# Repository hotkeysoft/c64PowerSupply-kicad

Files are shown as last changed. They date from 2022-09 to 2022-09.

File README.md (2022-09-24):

# C64 Power Supply
Rev B September 2022

### Basic Tests: complete

This was version was built and tested 40 minutes @ 2.5A on the 5V line with no issue. 
- Heat dissipation could be a problem in an plastic enclosure, will need more tests.
  - Regulator dissipates heat through ground plane so a metal case (and metal stand-offs) could be enough

### Simple Switching Power Supply
- 120/240VAC Input (toggle with jumpers)
- Beefier transformer (56VA)
- TVS diodes on both transformer output lines (optional)
- MOV and filtering cap on input side (optional)
- 9VAC Output 1.5A Max w/Fuse
- 5VDC Output 3A Max w/Fuse, more than enough for C128
- +5V Adjustable with trimmer
- BD9E303EFJ Buck switching regulator for +5V output
  - In theory more efficient than old LM2596T, tests will tell 
- Two terminal blocks to use the power supply with either a C64 or a C128
  - *NOT* at the same time...
    - 9VAC line should be fine in theory (transformer can provide 3A). Altough noise/crosstalk could be an issue.
    - 5V line could overload. The max capacity of this switching regulator is 3A. C128 uses around 2A by itself, with nothing connected. C64 is rated to use 1.5A. Not responsible if someone powers both at the same time.

Images
============
|Front | Back |
|---|---|
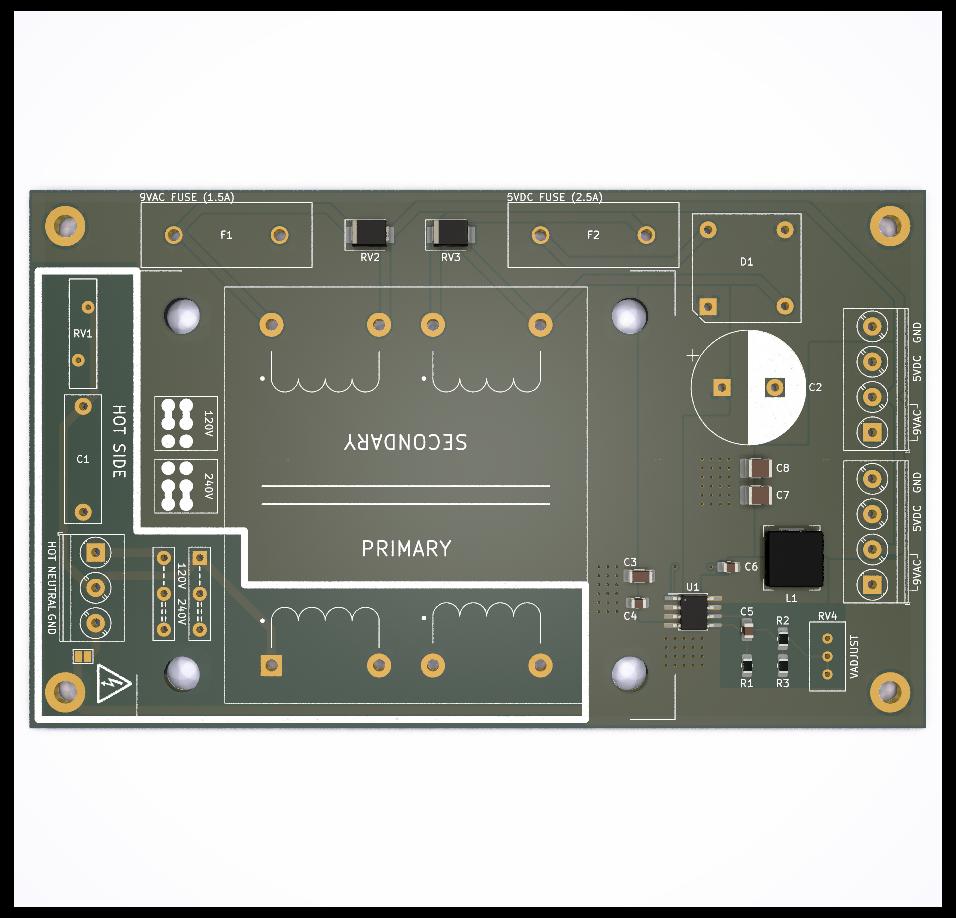
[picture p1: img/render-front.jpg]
Render Front
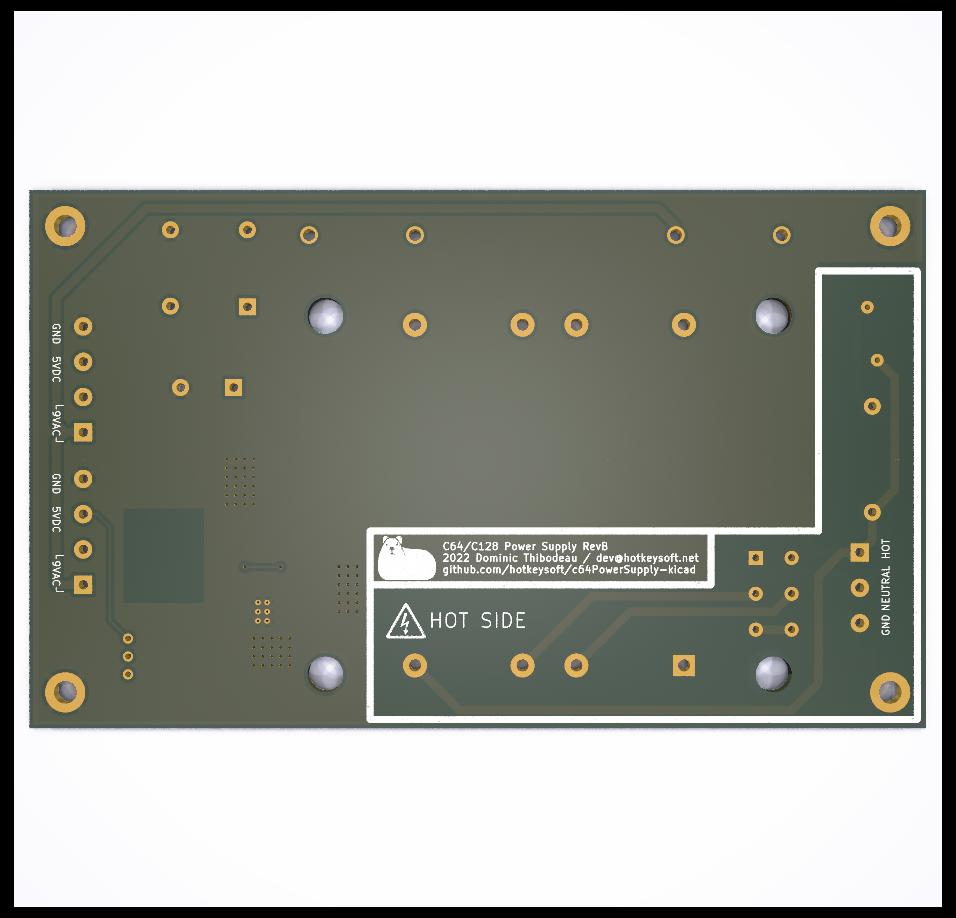
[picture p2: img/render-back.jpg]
Render Back
|||

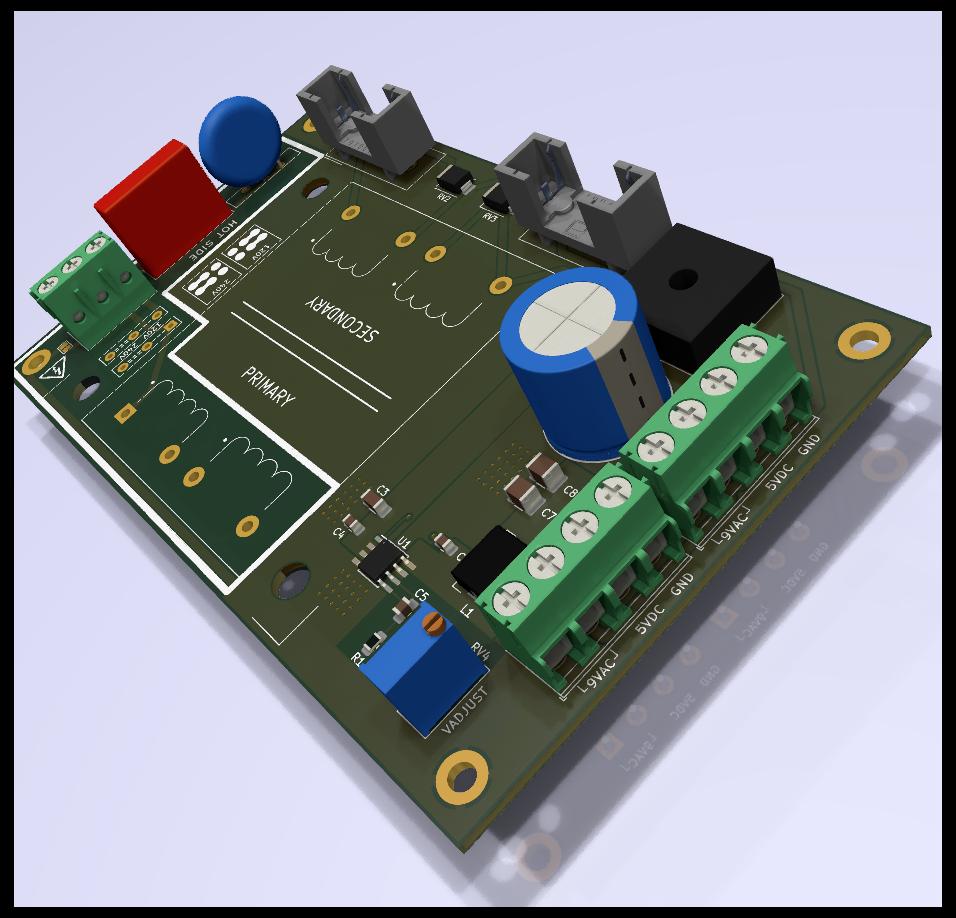
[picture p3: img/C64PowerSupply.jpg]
Render


### Schematics (pdf)
- [Complete schematics](./img/schema.pdf)

### PCB Images (svg)
- [Top](./img/pcb-front.svg)
- [Bottom](./img/pcb-back.svg)

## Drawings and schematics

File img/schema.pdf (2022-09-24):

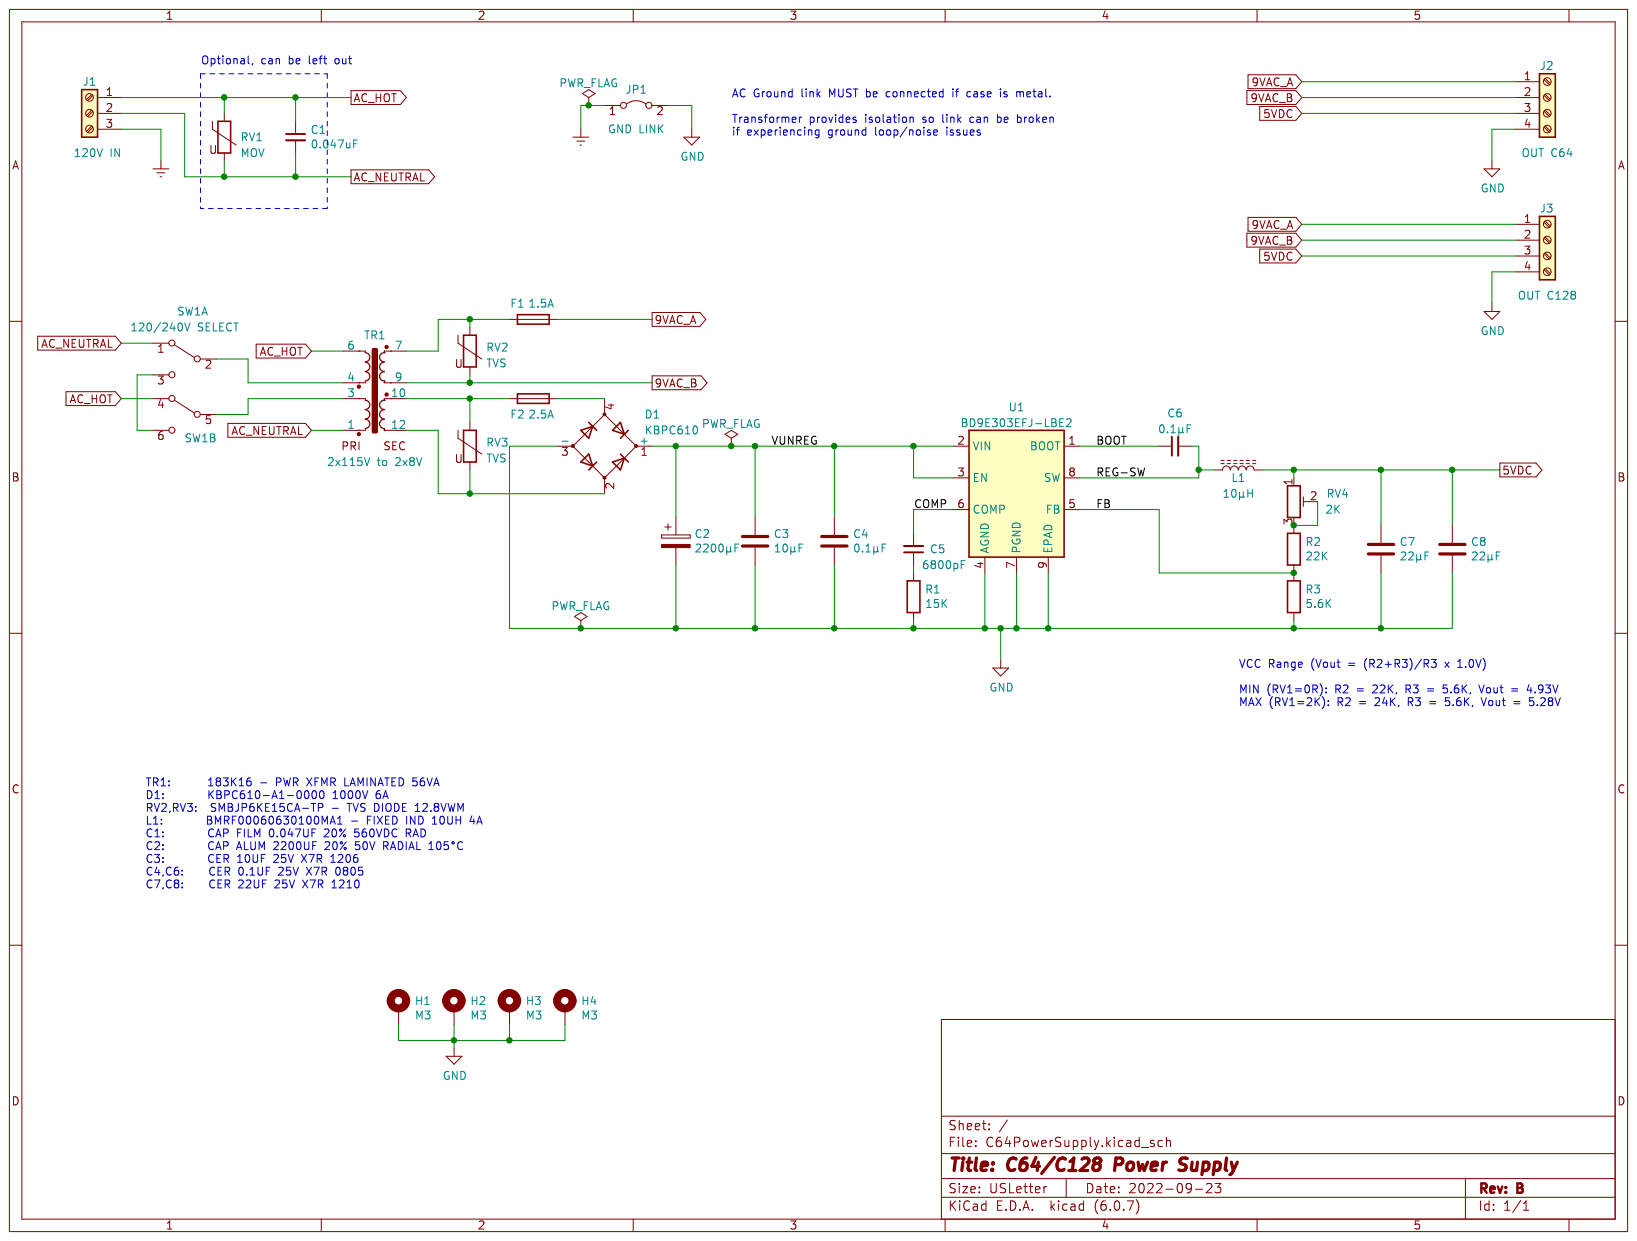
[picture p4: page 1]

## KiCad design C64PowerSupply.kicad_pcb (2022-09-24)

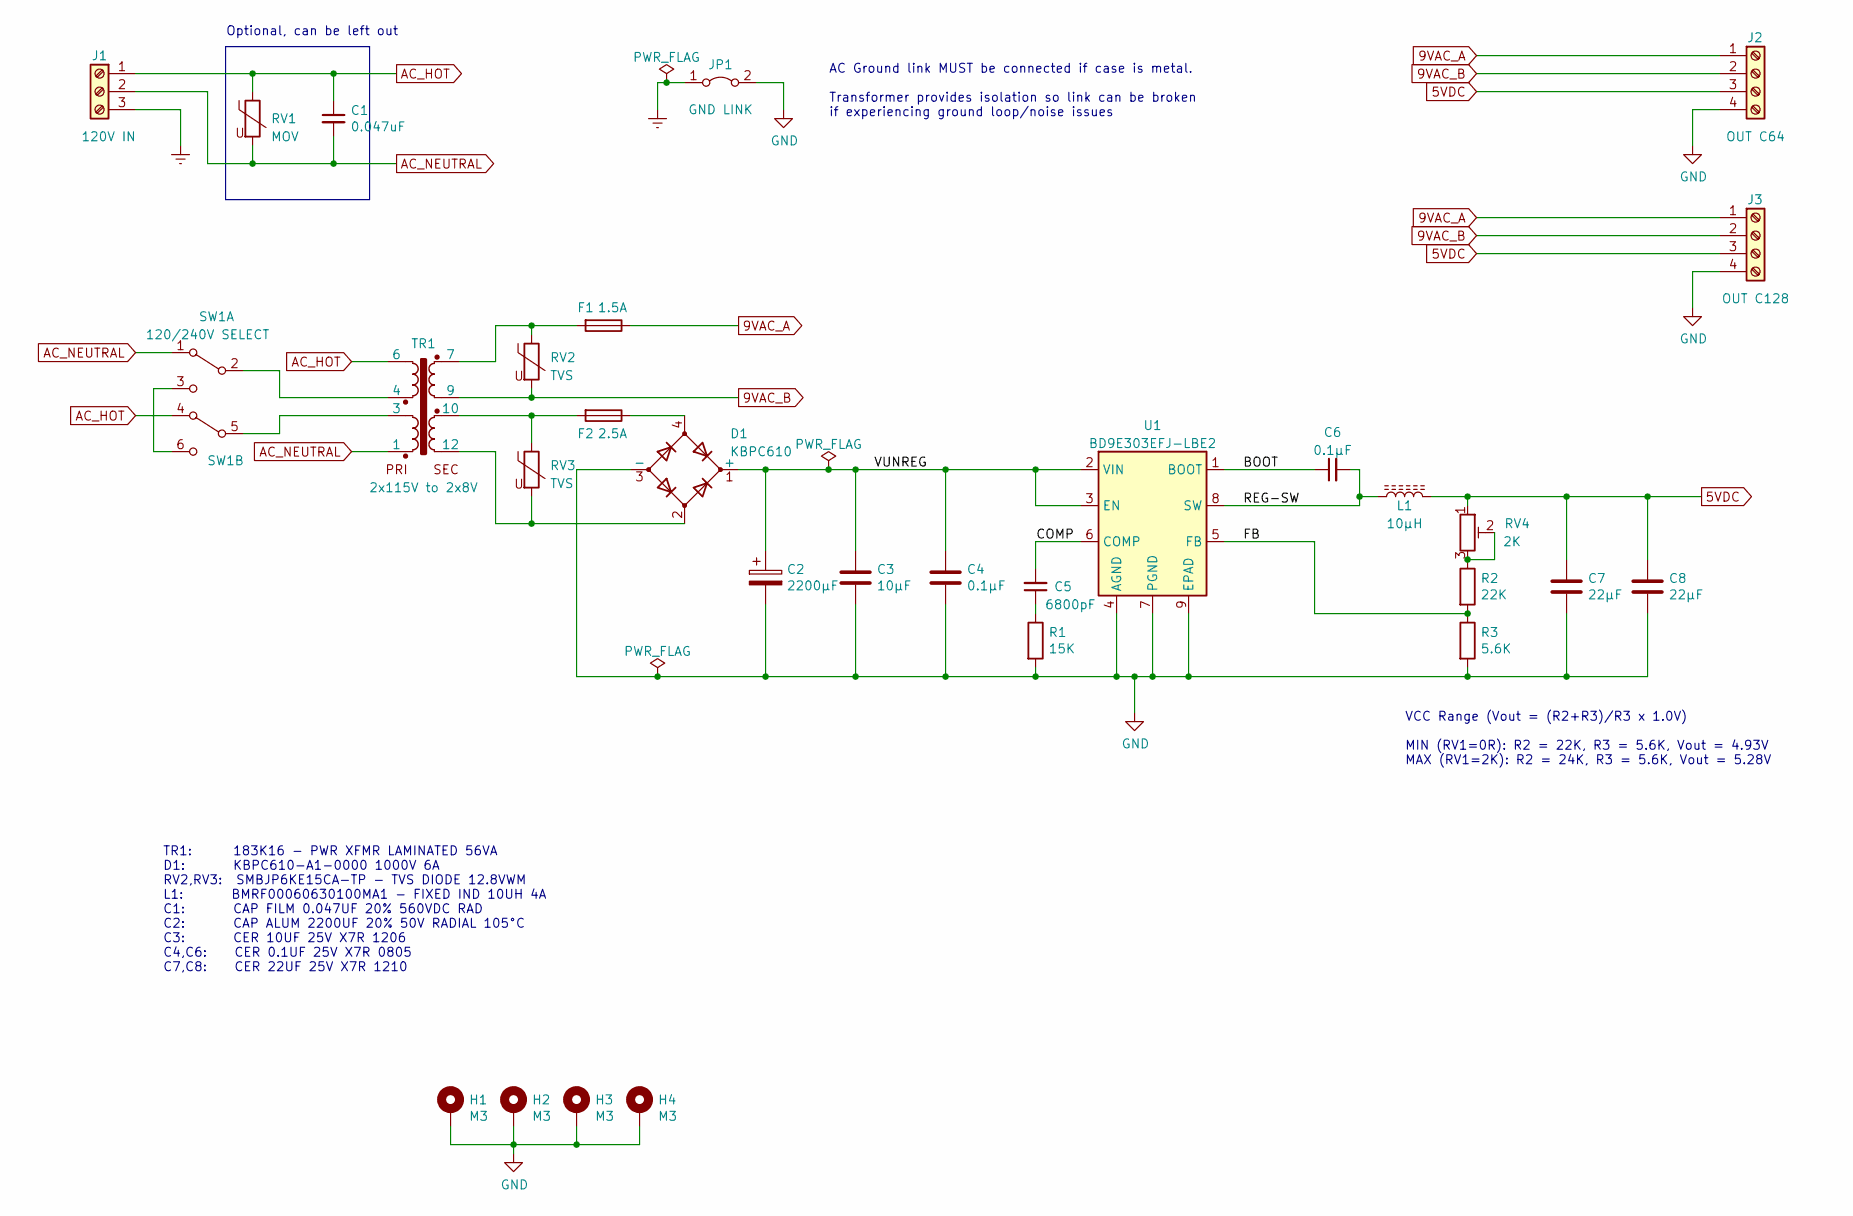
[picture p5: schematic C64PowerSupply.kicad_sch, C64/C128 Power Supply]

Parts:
C1: 0.047uF; C_Rect_L18.0mm_W5.0mm_P15.00mm_FKS3_FKP3
C2: 2200μF; CP_Radial_D16.0mm_P7.50mm
C3: 10μF; C_1206_3216Metric_Pad1.33x1.80mm_HandSolder
C4, C6: 0.1μF; C_0805_2012Metric_Pad1.18x1.45mm_HandSolder
C5: 6800pF; C_0805_2012Metric_Pad1.18x1.45mm_HandSolder
C7, C8: 22μF; C_1210_3225Metric_Pad1.33x2.70mm_HandSolder
D1: KBPC610; Diode_Bridge_15.1x15.1x6.3mm_P10.9mm
F1: 1.5A; Fuse_PTF-76
F2: 2.5A; Fuse_PTF-76
H1, H2, H3, H4: M3; MountingHole_3.2mm_M3_ISO7380_Pad
J1: 120V IN; TerminalBlock_Phoenix_PT-1,5-3-5.0-H_1x03_P5.00mm_Horizontal
J2: OUT C64; TerminalBlock_Phoenix_PT-1,5-4-5.0-H_1x04_P5.00mm_Horizontal
J3: OUT C128; TerminalBlock_Phoenix_PT-1,5-4-5.0-H_1x04_P5.00mm_Horizontal
JP1: GND LINK; SolderJumper-2_P1.3mm_Bridged_Pad1.0x1.5mm
L1: 10μH; L_BMRx00060630
R1: 15K; R_0805_2012Metric_Pad1.20x1.40mm_HandSolder
R2: 22K; R_0805_2012Metric_Pad1.20x1.40mm_HandSolder
R3: 5.6K; R_0805_2012Metric_Pad1.20x1.40mm_HandSolder
RV1: MOV; RV_Disc_D15.5mm_W3.9mm_P7.5mm
RV2, RV3: TVS; D_SMB
RV4: 2K; Potentiometer_Bourns_3296W_Vertical
SW1: 120/240V SELECT; V_SEL_SWITCH
TR1: 2x115V to 2x8V; Transformer_Hammond_183K16
U1: BD9E303EFJ-LBE2; Texas_HTSOP-8-1EP_3.9x4.9mm_P1.27mm_EP2.95x4.9mm_Mask2.4x3.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

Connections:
5VDC: C7.1, C8.1, J2.3, J3.3, L1.2, RV4.1
9VAC_A: F1.1, J2.1, J3.1
9VAC_B: J2.2, J3.2, RV2.2, TR1.9
/BOOT: C6.1, U1.1 (BOOT)
/COMP: C5.2, U1.6 (COMP)
/FB: R2.2, R3.1, U1.5 (FB)
/REG-SW: C6.2, L1.1, U1.8 (SW)
/VUNREG: C2.1, C3.1, C4.1, D1.1 (+), U1.2 (VIN), U1.3 (EN)
AC_HOT: C1.1, J1.1, RV1.1, SW1.4 (A), TR1.6
AC_NEUTRAL: C1.2, J1.2, RV1.2, SW1.1 (A), TR1.1
Earth: J1.3, JP1.1 (A)
GND: C2.2, C3.2, C4.2, C7.2, C8.2, D1.3 (-), H1.1, H2.1, H3.1, H4.1, J2.4, J3.4, JP1.2 (B), R1.2, R3.2, U1.4 (AGND), U1.7 (PGND), U1.9 (EPAD)
unnamed: C5.1, R1.1
unnamed: D1.2, RV3.2, TR1.12
unnamed: D1.4, F2.1
unnamed: F1.2, RV2.1, TR1.7
unnamed: F2.2, RV3.1, TR1.10
unnamed: R2.1, RV4.2, RV4.3
unnamed: SW1.2 (B), TR1.4
unnamed: SW1.3 (C), SW1.6 (C)
unnamed: SW1.5 (B), TR1.3

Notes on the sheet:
AC Ground link MUST be connected if case is metal. Transformer provides isolation so link can be broken if experiencing ground loop/noise issues
VCC Range (Vout = (R2+R3)/R3 x 1.0V) MIN (RV1=0R): R2 = 22K, R3 = 5.6K, Vout = 4.93V MAX (RV1=2K): R2 = 24K, R3 = 5.6K, Vout = 5.28V
TR1: 183K16 - PWR XFMR LAMINATED 56VA D1: KBPC610-A1-0000 1000V 6A RV2,RV3: SMBJP6KE15CA-TP - TVS DIODE 12.8VWM L1: BMRF00060630100MA1 - FIXED IND 10UH 4A C1: CAP FILM 0.047UF 20% 560VDC RAD C2: CAP ALUM 2200UF 20% 50V RADIAL 105°C C3: CER 10UF 25V X7R 1206 C4,C6: CER 0.1UF 25V X7R 0805 C7,C8: CER 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
Optional, can be left out

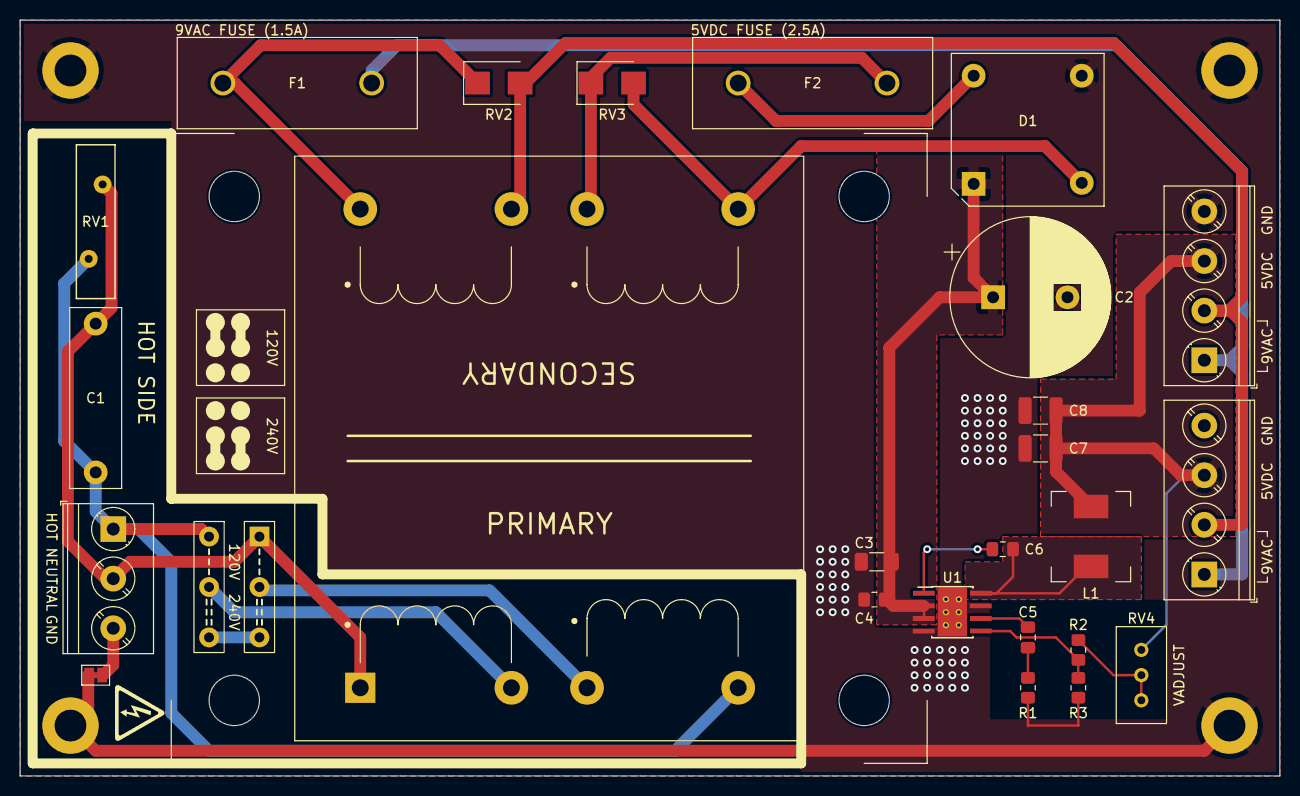
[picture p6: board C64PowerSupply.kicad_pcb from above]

Board: 2 copper layers, 127.0 x 76.2 mm, 30 parts (0 on the bottom side), 21 nets.

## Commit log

2021-06-27 Footprints, layout
    [C64PowerSupply.kicad_pcb, C64PowerSupply.sch]
2021-06-27 RevA Plot files
    [C64PowerSupply-B_Cu.gbr, C64PowerSupply-B_Mask.gbr, C64PowerSupply-B_SilkS.gbr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]
2021-07-01 Added trimpot. Routing
    [C64PowerSupply.kicad_pcb, C64PowerSupply.sch]
2021-07-01 Update plot
    [C64PowerSupply-B_Cu.gbl, C64PowerSupply-B_Cu.gbr, C64PowerSupply-B_Mask.gbr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]
2022-09-06 Kicad6 upgrade
    [C64PowerSupply.kicad_pcb, C64PowerSupply.kicad_sch, C64PowerSupply.sch]
2022-09-18 Begin route
    [C64PowerSupply.kicad_pcb, C64PowerSupply.kicad_sch]
2022-09-18 Cleanup, fix 120/240V switch
    [C64PowerSupply.kicad_pcb, C64PowerSupply.kicad_sch]
2022-09-18 Transformer hole size
    [C64PowerSupply.kicad_pcb]
2022-09-18 Voltage sel switch footprint
    [C64PowerSupply.kicad_pcb, C64PowerSupply.kicad_sch]
2022-09-18 Move cap, add logo
    [C64PowerSupply.kicad_pcb]
2022-09-18 Plot, images, README, Fix ground plane
    [C64PowerSupply-B_Cu.gbl, C64PowerSupply-B_Mask.gbs, C64PowerSupply-B_SilkS.gbo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]
2022-09-24 Bumped C2 to 2200uF
    1000uF worked fine @ 2A but regulation dropped quickly after
    because ripple was too large. 2200uF is enough to go up to 3A.
    [C64PowerSupply.kicad_pcb, C64PowerSupply.kicad_sch]
